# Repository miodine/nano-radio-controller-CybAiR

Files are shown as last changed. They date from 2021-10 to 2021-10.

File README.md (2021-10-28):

# nano-radio-controller-CybAiR
Beginner electronics project - 433MHz &amp; 2.4GHz RC transmitter based on Arduino Nano board (Hardware layout + Software).
Designed and built as a part of the activity in CybAiR SC; Poznan University of Technology.



!

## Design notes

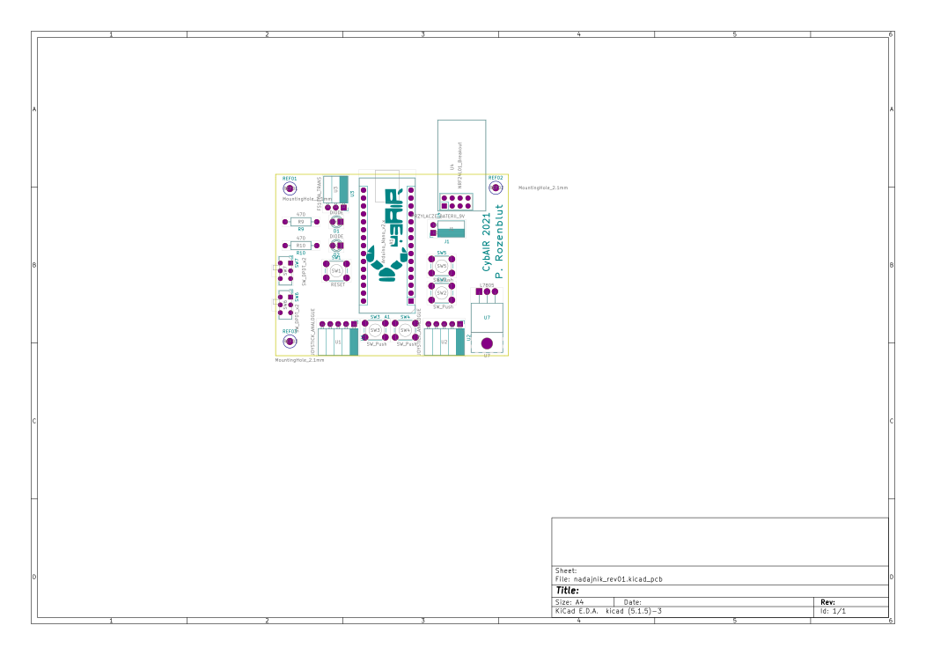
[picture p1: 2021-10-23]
hardware/nadajnik_rev01/odniesienie_svg/nadajnik_rev01-brd.png

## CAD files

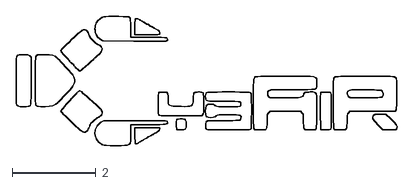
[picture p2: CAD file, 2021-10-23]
hardware/nadajnik_rev01/cybair_logo_vector.dxf
9.08 x 3.08

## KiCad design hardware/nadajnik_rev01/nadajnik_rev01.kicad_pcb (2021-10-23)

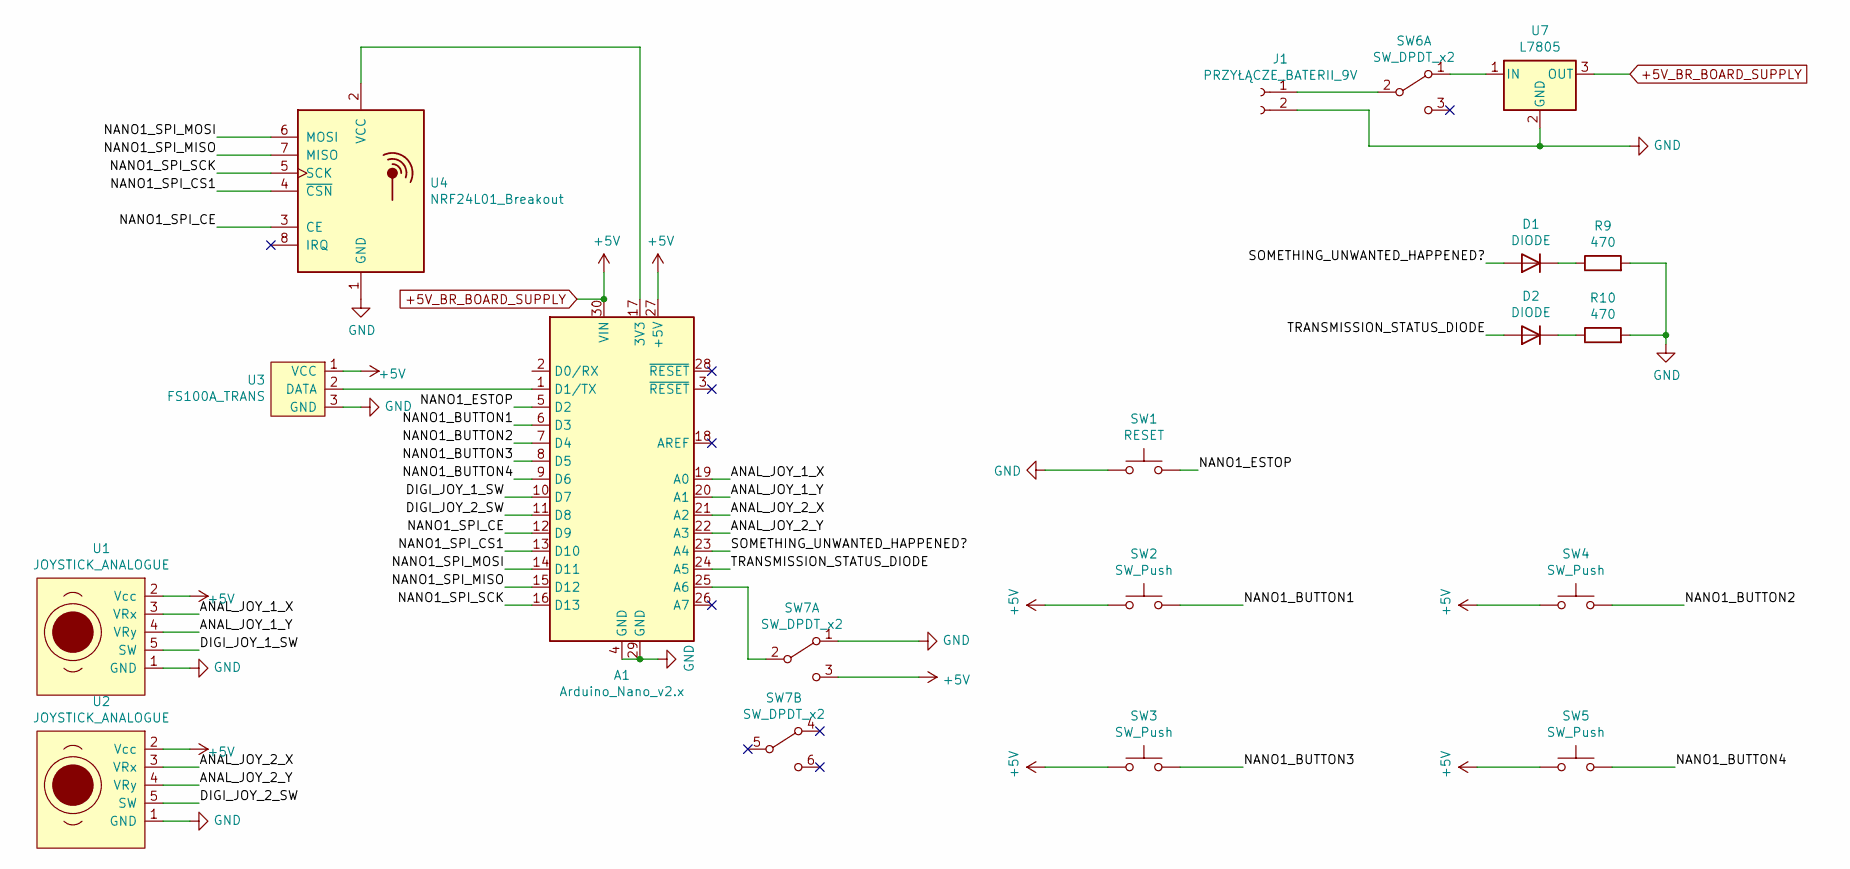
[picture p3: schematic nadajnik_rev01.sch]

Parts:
A1: Arduino_Nano_v2.x; Arduino_Nano
D1, D2: DIODE; LED_D3.0mm_IRGrey
J1: PRZYŁĄCZE_BATERII_9V; PinSocket_1x02_P2.54mm_Horizontal
R9, R10: 470; R_Axial_DIN0207_L6.3mm_D2.5mm_P10.16mm_Horizontal
SW1: RESET; SW_PUSH_6mm_H13mm
SW2, SW3, SW4, SW5: SW_Push; SW_PUSH_6mm_H13mm
SW6, SW7: SW_DPDT_x2; SW_CuK_JS202011AQN_DPDT_Angled
U1, U2: JOYSTICK_ANALOGUE; PinSocket_1x05_P2.54mm_Horizontal
U3: FS100A_TRANS; PinSocket_1x03_P2.54mm_Horizontal
U4: NRF24L01_Breakout; nRF24L01_Breakout
U7: L7805; TO-220-3_Horizontal_TabUp

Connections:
+5V_BR_BOARD_SUPPLY: A1.27 (+5V), A1.30 (VIN), SW2.1, SW3.1, SW4.1, SW5.1, SW7.3 (C), U1.2 (Vcc), U2.2 (Vcc), U3.1 (VCC), U7.3 (OUT)
/ANAL_JOY_1_X: A1.19 (A0), U1.3 (VRx)
/ANAL_JOY_1_Y: A1.20 (A1), U1.4 (VRy)
/ANAL_JOY_2_X: A1.21 (A2), U2.3 (VRx)
/ANAL_JOY_2_Y: A1.22 (A3), U2.4 (VRy)
/DIGI_JOY_1_SW: A1.10 (D7), U1.5 (SW)
/DIGI_JOY_2_SW: A1.11 (D8), U2.5 (SW)
/NANO1_BUTTON1: A1.6 (D3), SW2.2
/NANO1_BUTTON2: A1.7 (D4), SW4.2
/NANO1_BUTTON3: A1.8 (D5), SW3.2
/NANO1_BUTTON4: A1.9 (D6), SW5.2
/NANO1_ESTOP: A1.5 (D2), SW1.2
/NANO1_SPI_CE: A1.12 (D9), U4.3 (CE)
/NANO1_SPI_CS1: A1.13 (D10), U4.4 (~CSN)
/NANO1_SPI_MISO: A1.15 (D12), U4.7 (MISO)
/NANO1_SPI_MOSI: A1.14 (D11), U4.6 (MOSI)
/NANO1_SPI_SCK: A1.16 (D13), U4.5 (SCK)
/SOMETHING_UNWANTED_HAPPENED?: A1.23 (A4), D1.1 (A)
/TRANSMISSION_STATUS_DIODE: A1.24 (A5), D2.1 (A)
GND: A1.4 (GND), A1.29 (GND), J1.2, R9.2, R10.2, SW1.1, SW7.1 (A), U1.1 (GND), U2.1 (GND), U3.3 (GND), U4.1 (GND), U7.2 (GND)
unnamed: A1.1 (D1/TX), U3.2 (DATA)
unnamed: A1.17 (3V3), U4.2 (VCC)
unnamed: A1.25 (A6), SW7.2 (B)
unnamed: D1.2 (K), R9.1
unnamed: D2.2 (K), R10.1
unnamed: J1.1, SW6.2 (B)
unnamed: SW6.1 (A), U7.1 (IN)

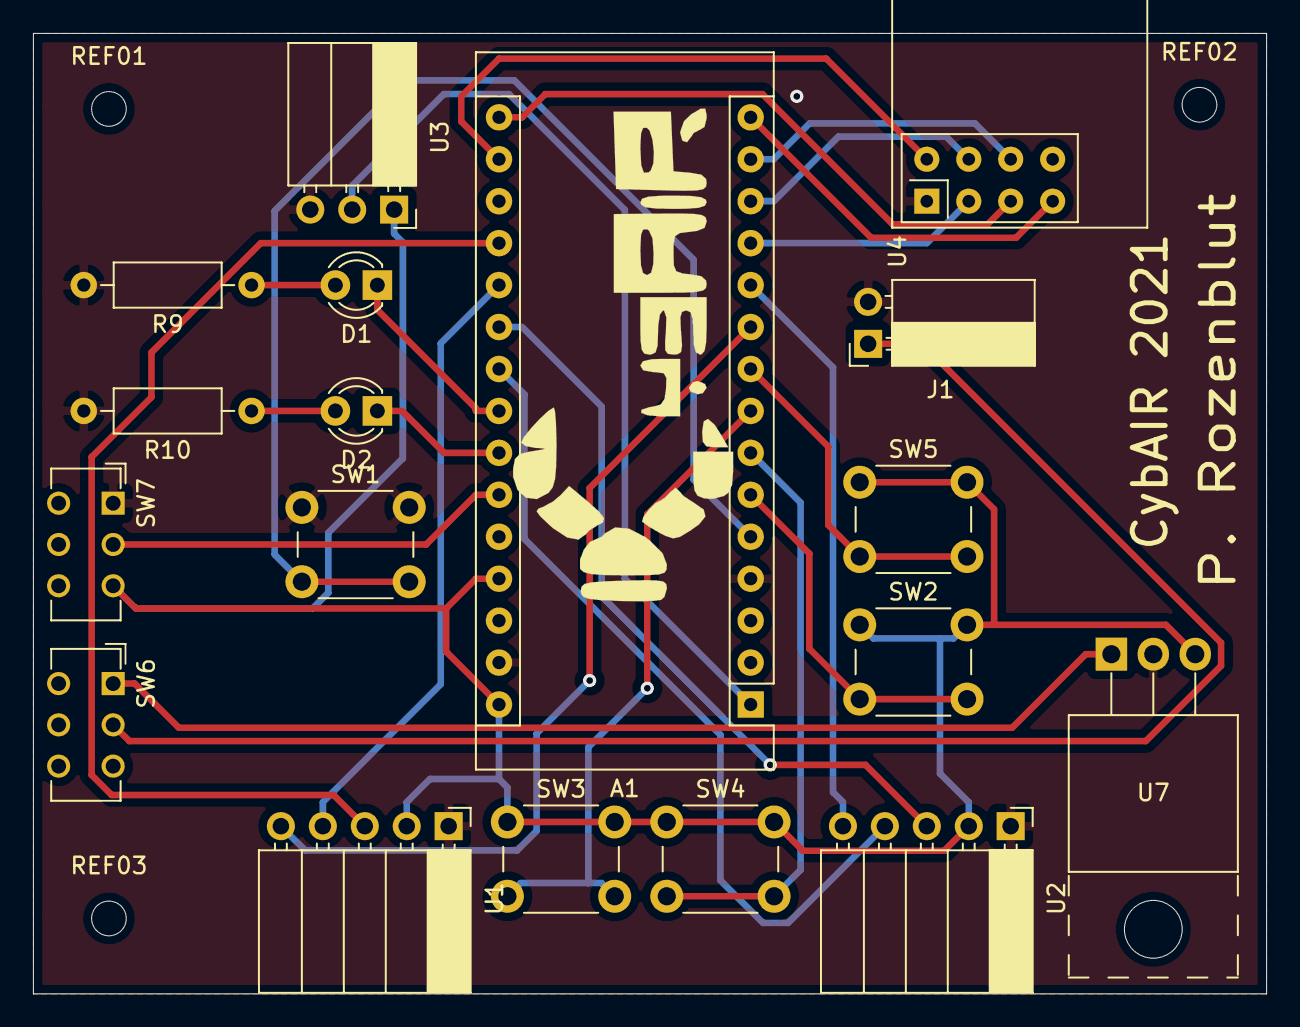
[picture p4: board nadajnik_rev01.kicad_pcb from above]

Board: 2 copper layers, 74.7 x 58.2 mm, 21 parts (0 on the bottom side), 27 nets.

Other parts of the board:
REF01, REF02, REF03: MountingHole_2.1mm

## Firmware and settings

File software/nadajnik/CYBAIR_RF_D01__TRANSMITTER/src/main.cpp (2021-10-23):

#include <Arduino.h>
#include <SPI.h>
#include <nRF24L01.h>
#include <RF24.h>
#include <RH_ASK.h>
#include <stdint.h>


#define CE_PIN   9
#define CSN_PIN 10

#define JOYSTICK_1_X A0
#define JOYSTICK_1_Y A1
#define JOYSTICK_2_X A2
#define JOYSTICK_2_Y A3

#define R433_TX 1
#define STATUS_LED 5

const uint64_t pipe = 0xE8E8F0F0E1LL; // dla 2.4 GHz

enum{
    MODE_RADIO_24G = 0,
    MODE_RADIO_433M,
    MODE_STOP
};


typedef enum STATUS_BYTE{
    N_E_STOP = 0x80,
    RADIO_433_SELECTED = 0x40, //do wyjebania
    BUTTON_J1_P = 0x20,
    BUTTON_J2_P = 0x10,
    BUTTON_S1_P = 0x08,
    BUTTON_S2_P = 0x04,
    BUTTON_S3_P = 0x02,
    BUTTON_S4_P = 0x01
} STATUS_BYTE;

RF24 radio_24G(CE_PIN, CSN_PIN);                      // 2.4 GHz 
RH_ASK radio_433M(2000, -1, R433_TX, -1);             // 433 MHz

unsigned long time_prev  = 0;
unsigned long time_now;
unsigned long time_delta = 50;
unsigned long ping_time = 0;
unsigned long ping_delta_time;


uint16_t joy_readout = 0;
uint8_t mode_ = MODE_RADIO_433M;

uint8_t tx_data[9] = {0, };


unsigned long dx1 = 0;
unsigned long dx2 = 0;

void update_status_byte(uint8_t* datum, STATUS_BYTE status)
{
  *datum |= status;
}

void evaluate_emergency_stop()
{
    mode_ = MODE_STOP;
    digitalWrite(A4,HIGH);
}

void evaluate_band_change()
{
  if( mode_ != MODE_STOP)
  {
    if(analogRead(A6) < 500) mode_ = MODE_RADIO_24G;
    else mode_ = MODE_RADIO_433M;
  }
}


void setup()  
{
  //INIT 2.4GHz MODULE
  radio_24G.begin();
  radio_24G.setDataRate(RF24_250KBPS);
  radio_24G.openWritingPipe(pipe);

  //INIT BUTTONS
  pinMode(7, INPUT_PULLUP); //D7 BUTTON
  pinMode(8, INPUT_PULLUP); //D8 BUTTON

  pinMode(6, INPUT);
  pinMode(5,INPUT);
  pinMode(4, INPUT);
  pinMode(3,INPUT);
  

  pinMode(2, INPUT_PULLUP);

  
  attachInterrupt(digitalPinToInterrupt(2), evaluate_band_change, LOW);
  //STATUS 
  pinMode(A4,OUTPUT);
  pinMode(A5,OUTPUT);
  
  if(!radio_433M.init()){}
  
}


void loop() 
{
  tx_data[0] = 0x00;
  if(mode_ != MODE_STOP) 
  {
    update_status_byte(&tx_data[0], N_E_STOP);
  }


  evaluate_band_change();

  joy_readout = (uint16_t)analogRead(JOYSTICK_1_X);
  tx_data[1] = (uint8_t)(joy_readout >> 8);
  tx_data[2] = (uint8_t)joy_readout;
  
  joy_readout = (uint16_t)analogRead(JOYSTICK_1_Y);
  tx_data[3] = (uint8_t)(joy_readout >> 8);
  tx_data[4] = (uint8_t)joy_readout;

  joy_readout = (uint16_t)analogRead(JOYSTICK_2_X);
  tx_data[5] = (uint8_t)(joy_readout >> 8);
  tx_data[6] = (uint8_t)joy_readout;

  joy_readout = (uint16_t)analogRead(JOYSTICK_2_Y);
  tx_data[7] = (uint8_t)(joy_readout >> 8);
  tx_data[8] = (uint8_t)joy_readout;

  if(digitalRead(7)==LOW) update_status_byte(&tx_data[0],BUTTON_J1_P);  
  if(digitalRead(8)==LOW) update_status_byte(&tx_data[0],BUTTON_J2_P); 

  if(analogRead(3)==HIGH) update_status_byte(&tx_data[0],BUTTON_S1_P); 
  if(digitalRead(4)==HIGH) update_status_byte(&tx_data[0],BUTTON_S2_P); 
  if(digitalRead(5)==HIGH) update_status_byte(&tx_data[0],BUTTON_S3_P); 
  if(digitalRead(6)==HIGH) update_status_byte(&tx_data[0],BUTTON_S4_P); 


  switch (mode_)
  {
  case MODE_RADIO_24G:
    digitalWrite(A5,HIGH);
    radio_24G.write(tx_data, sizeof(tx_data));
    digitalWrite(A5,LOW);
    break;
    
  case MODE_RADIO_433M:
    digitalWrite(A5,HIGH);
    update_status_byte(&tx_data[0], RADIO_433_SELECTED);
    radio_433M.send(tx_data, sizeof(tx_data));
    radio_433M.waitPacketSent();
    digitalWrite(A5,LOW);
    break;

  default: //CASE ESTOP -> COMUNICATE IT ON BOTH CHANNELS
    radio_24G.write(tx_data, sizeof(tx_data));
    update_status_byte(&tx_data[0], RADIO_433_SELECTED);
    radio_433M.send(tx_data, sizeof(tx_data));
    radio_433M.waitPacketSent();
    break;
  }

  time_now = millis();

  while((time_now - time_prev)<time_delta)
  {
    time_now = millis();
  }
  time_prev = millis();
}

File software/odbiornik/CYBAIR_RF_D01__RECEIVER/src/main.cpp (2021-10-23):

#include <su_radio_hfunc.hpp>
#include <main.h>


RF24 r24G(CE_PIN, CSN_PIN);                     // Create a Radio 2.4 GHz
RH_ASK r433M(2000, RX_433_PIN, -1 , -1);        // Create a radio 433 MHz
IBus ibus(NUM_CHANNELS);

su_radio radiox;




void setup()   
{
  Serial.begin(BAUD_RATE);
  radiox.radio_init(&r24G, &r433M);
}

void loop()  
{
    radiox.receive_data(&r24G, &r433M);

    radiox.ibus_transmit_data(&ibus);
}
